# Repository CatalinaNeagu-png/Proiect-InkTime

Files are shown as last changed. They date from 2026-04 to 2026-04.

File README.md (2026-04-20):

# Proiect-InkTime
## 1. Diagrama Bloc a Sistemului
Diagrama de mai jos arata cum sunt conectate componentele principale la microcontroller-ul nRF52840:

- **Alimentare:** USB-C -> BQ25180 (Charger) -> Baterie LiPo 400mAh.
- **Afisaj:** Ecran E-Paper 1.54 inch (Conectat prin SPI).
- **Senzori:** Accelerometru BMA423 (Conectat prin I2C).
- **Haptica:** Driver DRV2605 + Motor Vibratii (Conectat prin I2C).
- **Interactiune:** 3 Butoane Tactile (Conectate prin GPIO).
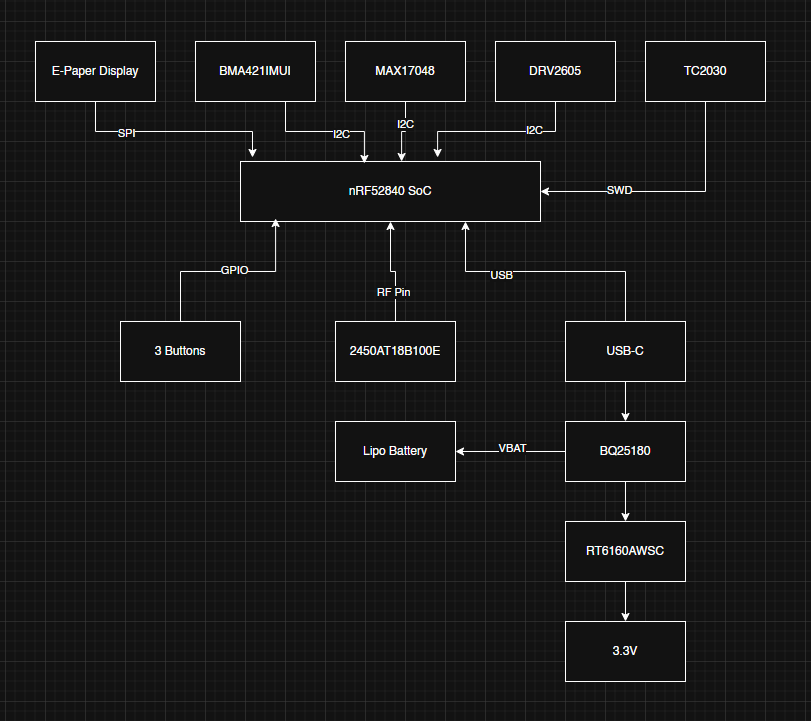
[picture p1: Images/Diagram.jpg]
Diagram


## 2. Bill of Materials (BOM)
Componente selectate din catalogul JLCPCB:

| Componenta | Producator | JLC Part Number | Datasheet |
| :--- | :--- | :--- | :--- |
| MCU nRF52840 | Nordic Semi | C190733 | [Datasheet](https://infocenter.nordicsemi.com/pdf/nRF52840_PS_v1.0.pdf) |
| Senzor BMA423 | Bosch | C404044 | [Datasheet](https://www.bosch-sensortec.com/media/boschsensortec/downloads/datasheets/bst-bma423-ds004.pdf) |
| Charger BQ25180 | TI | C2907481 | [Datasheet](https://www.ti.com/lit/ds/symlink/bq25180.pdf) |
| Driver DRV2605L | TI | C63523 | [Datasheet](https://www.ti.com/lit/ds/symlink/drv2605l.pdf) |
| Antena 2.45GHz | Johanson | C105252 | [Datasheet](https://www.johansontechnology.com/datasheets/2450AT18B100.pdf) |

## 3. Functionalitate Hardware
Dispozitivul foloseste nRF52840 pentru gestionarea comunicatiei Bluetooth Low Energy.

- **Display E-Paper:** Foloseste interfata **SPI**. Avantajul principal este consumul de energie zero cand imaginea este statica.
- **Senzori:** Accelerometrul BMA423 (interfata **I2C**) detecteaza miscarea si pasii.
- **Haptica:** Driverul DRV2605L (interfata **I2C**) controleaza motorul de vibratii pentru alerte.
- **Consum:** S-a calculat un consum in standby de aproximativ 20uA, ceea ce asigura o durata de viata a bateriei de peste 30 de zile.

## 4. Mapare Pini nRF52840

| Functie | Pin nRF | Interfata | Justificare |
| :--- | :--- | :--- | :--- |
| SPI SCK | P0.20 | SPI | Ceas pentru ecran |
| SPI MOSI | P0.21 | SPI | Date pentru ecran |
| SPI CS | P0.22 | SPI | Selectie ecran |
| I2C SDA | P0.26 | I2C | Date senzori/charger |
| I2C SCL | P0.27 | I2C | Ceas senzori/charger |
| Buton Sus | P0.11 | GPIO | Intrare navigare |
| Buton OK | P0.12 | GPIO | Intrare selectie |
| Buton Jos | P0.13 | GPIO | Intrare navigare |

## 5. Design si Integrare Mecanica
- **Aliniere:** Butoanele tactile sunt plasate la Y=3mm pentru a se potrivi cu decupajele carcasei WearAware.
- **Antena:** Are o zona dedicata "keep-out" fara cupru pentru a nu bloca semnalul Bluetooth.
- **Asamblare:** Componentele sunt asezate tip "sandwich": Carcasa -> Display -> PCB -> Baterie.

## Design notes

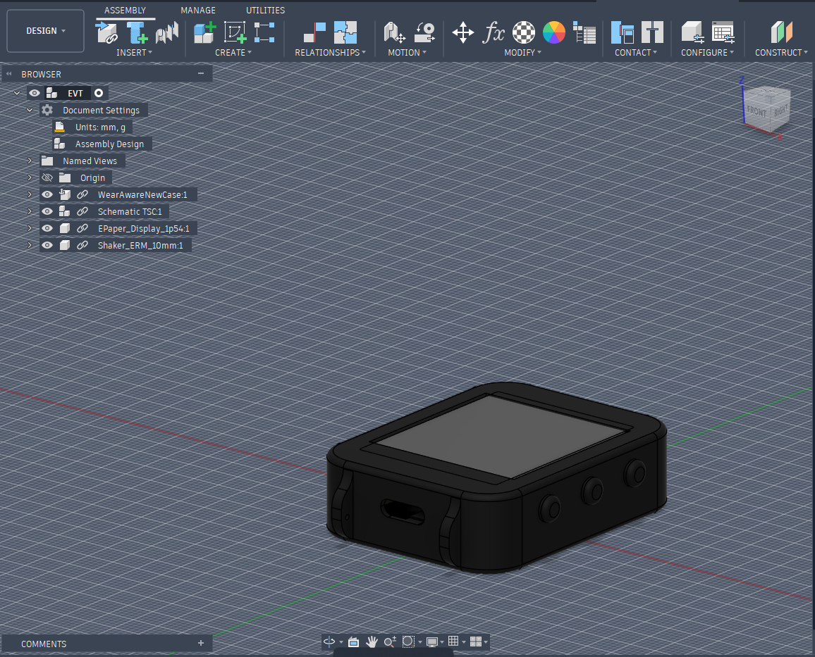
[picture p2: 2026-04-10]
Images/Screenshot 2026-04-10 175402.png

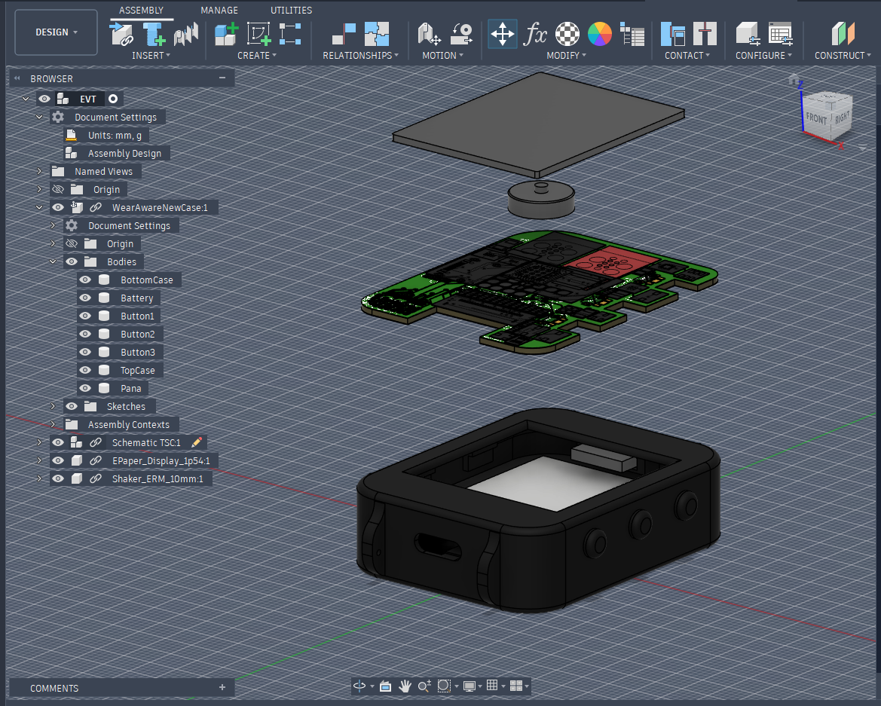
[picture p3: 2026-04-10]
Images/Screenshot 2026-04-10 174944.png

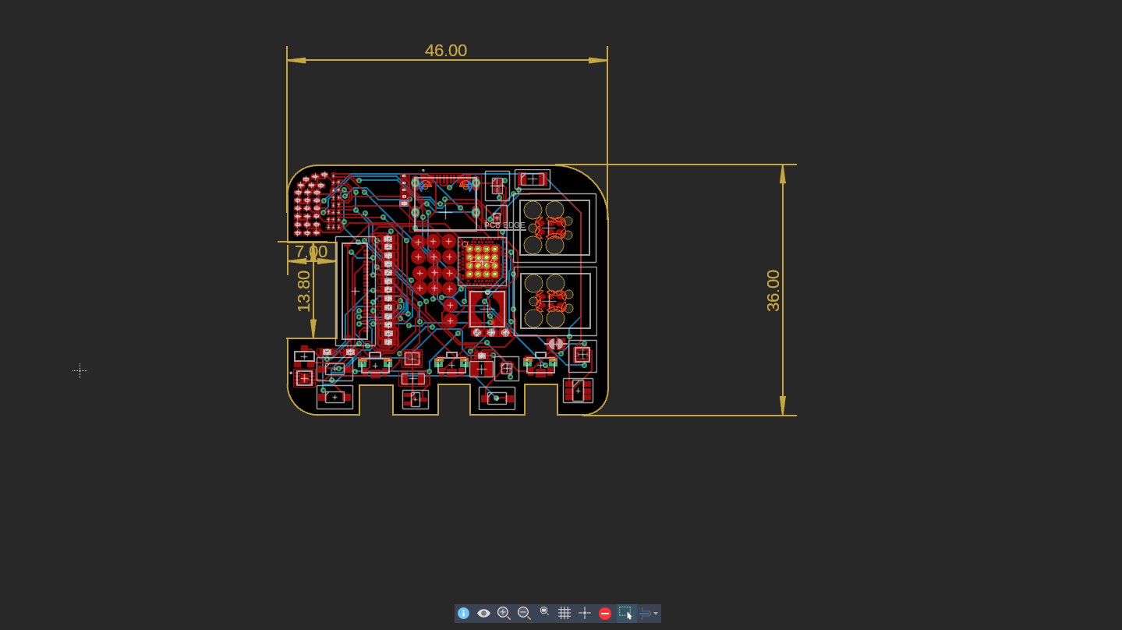
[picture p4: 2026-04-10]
Images/Screenshot 2026-04-10 175436.png

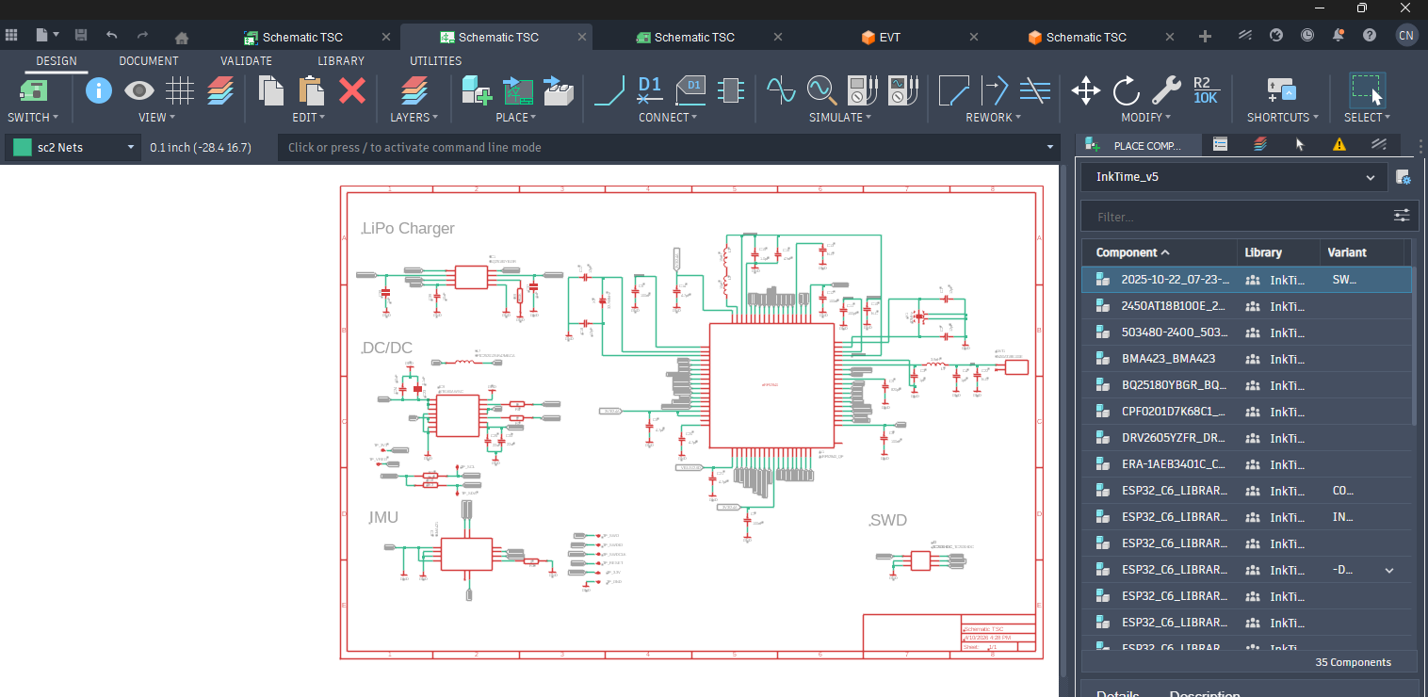
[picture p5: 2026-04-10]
Images/Screenshot 2026-04-10 175542.png

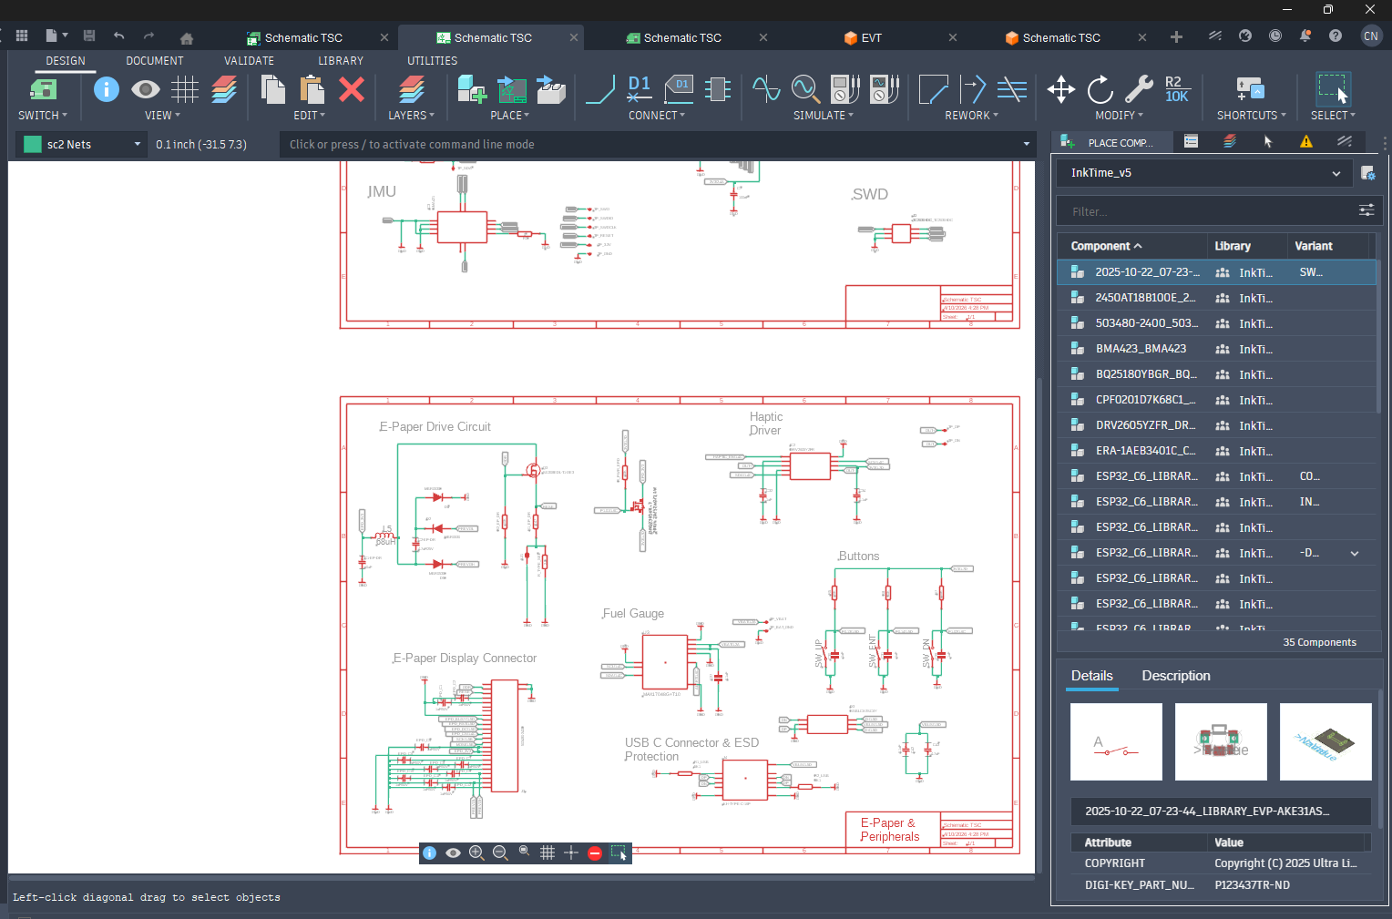
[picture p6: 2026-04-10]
Images/Screenshot 2026-04-10 175555.png

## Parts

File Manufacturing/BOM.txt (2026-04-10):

Partlist exported from Fusion Hub: Laborator TSC   Project: Default Project  Board: Schematic TSC at 4/10/2026 5:35 PM

Qty Value                                                   Device                                                                       Package                                                                                                                Parts                                                                                                                      Description                                                                                                               ARROW_PART_NUMBER ARROW_PRICE-STOCK                                                                                AVAILABILITY CHECK_PRICES                                                                       COPYRIGHT                                                DESCRIPTION                                                                                                                                                                         DIGI-KEY_PART_NUMBER_1                    DIGI-KEY_PART_NUMBER_2 DIGI-KEY_PART_NUMBER_3                              HEIGHT  JLCPCB MANUFACTURER_NAME   MANUFACTURER_PART_NUMBER                                         MF                 MFR_NAME          MOUSER_PART_NUMBER MOUSER_PRICE-STOCK                                                                                           MP                                                                                                       PACKAGE                     POPULARITY PRICE            PROD_ID                      PURCHASE-URL                                                                                                                               SNAPEDA_LINK                                                                      SPICEMODEL SPICEPREFIX                                                                                                                                     TP_SIGNAL_NAME                                                                      VALUE             
1                                                           ESP32_C6_LIBRARY_7_JUMPER_SJ                                                 ESP32_C6_LIBRARY_7_JUMPER_SJ                                                                                           SJ1                                                                                                                        SMD solder JUMPER                                                                                                                                                                                                                                                                                                                                                                                                                                                                                                                                                                                                                                                                                                                                                                                                                                                                                                                                                                                                                                                                                                            3                                                                                                                                                                                                                                                                                                                                                                                                                                                                                                                                                      
3   0                                                       CPF0201D7K68C1_CPF0201D7K68C1                                                CPF0201D7K68C1_0201                                                                                                    R2, R3, R4                                                                                                                 7.68k 0201 Thin Film Surface Mount Fixed Resistor +/-0.5% 0.031W CPF0201D7K68C1                                                                                                                                                                                                                                                                                                                                                                                                                                                                                                                                                                                                                                                                                                                                                                                                                                                                                                                                                                                                                                                                                                                                                                                                                                                                                                                                                                                                                                                                                                                                                                                                     
2   0.1uF                                                   ESP32_C6_LIBRARY_1_ESP32_WROVER_EAGLE-LTSPICE_CC0402                         ESP32_C6_LIBRARY_1_ESP32_WROVER_EAGLE-LTSPICE_C0402                                                                    C34, C42                                                                                                                   CAPACITOR, European symbol                                                                                                                                                                                                                                                                                                                                                                                                                                                                                                                                                                                                                                                                                                                                                                                                                                                                                                                                                                                                                                                                                                                                                                                                                                                                                                                                                                                         NONE       C                                                                                                                                                                                                                                                     
1   0.1uF                                                   GRM011R60J152KE01L_1_GRM011R60J152KE01L                                      GRM011R60J152KE01L_1_0201                                                                                              C23                                                                                                                        Check availability                                                                                                                                                                                                                                                                                                                                                                                                                                                                                                                                                                                                                                                                                                                                                                                                                                                                                                                                                                                                                                                                                                                                                                                                                                                                                                                                                                                                                                                                                                                                                                                                                                                                  
1   0.1uF                                                   GRM011R60J152KE01L_2_GRM011R60J152KE01L                                      GRM011R60J152KE01L_2_CAPC0201X13N                                                                                      C27                                                                                                                        Check availability                                                                                                                                                                                                                           In Stock     https://www.snapeda.com/parts/GRM011R60J152KE01L/Murata/view-part/?ref=eda                                                                                                                        SMD Capacitor X5R(EIA) with Capacitance: 1500pF Tol. 10%. Rated Voltage: 6.3Vdc                                                                                                                                                                                                                                                                        Murata                                                                                                                                                               GRM011R60J152KE01L                                                                                       0201 Murata                            None                                                                                                                                                                                     https://www.snapeda.com/parts/GRM011R60J152KE01L/Murata/view-part/?ref=snap                                                                                                                                                                                                                                                                        
1   0.47                                                    CPF0201D7K68C1_CPF0201D7K68C1                                                CPF0201D7K68C1_0201                                                                                                    R1_EP_DR                                                                                                                   7.68k 0201 Thin Film Surface Mount Fixed Resistor +/-0.5% 0.031W CPF0201D7K68C1                                                                                                                                                                                                                                                                                                                                                                                                                                                                                                                                                                                                                                                                                                                                                                                                                                                                                                                                                                                                                                                                                                                                                                                                                                                                                                                                                                                                                                                                                                                                                                                                     
1   1.0µF                                                   NORDIC_NRF_3_CAPACITOR_0201_L                                                NORDIC_NRF_3_RESC0201_L                                                                                                C15                                                                                                                        Generic chip capacitor                                                                                                                                                                                                                                                                                                                                                                                                                                                                                                                                                                                                                                                                                                                                                                                                                                                                                                                                                                                                                                                                                                                                                                                                                                                                                                                                                                                                                                                                                                                                                                                                                                                              
4   100nF                                                   NORDIC_NRF_3_CAPACITOR_0201_L                                                NORDIC_NRF_3_RESC0201_L                                                                                                C5, C7, C8, C12                                                                                                            Generic chip capacitor                                                                                                                                                                                                                                                                                                                                                                                                                                                                                                                                                                                                                                                                                                                                                                                                                                                                                                                                                                                                                                                                                                                                                                                                                                                                                                                                                                                                                                                                                                                                                                                                                                                              
1   100pF                                                   NORDIC_NRF_3_CAPACITOR_0201_L                                                NORDIC_NRF_3_RESC0201_L                                                                                                C11                                                                                                                        Generic chip capacitor                                                                                                                                                                                                                                                                                                                                                                                                                                                                                                                                                                                                                                                                                                                                                                                                                                                                                                                                                                                                                                                                                                                                                                                                                                                                                                                                                                                                                                                                                                                                                                                                                                                              
6   10K                                                     CPF0201D7K68C1_CPF0201D7K68C1                                                CPF0201D7K68C1_0201                                                                                                    R2_EP_DR, R5, R7, R8, R9, R_PWR_EPD                                                                                        7.68k 0201 Thin Film Surface Mount Fixed Resistor +/-0.5% 0.031W CPF0201D7K68C1                                                                                                                                                                                                                                                                                                                                                                                                                                                                                                                                                                                                                                                                                                                                                                                                                                                                                                                                                                                                                                                                                                                                                                                                                                                                                                                                                                                                                                                                                                                                                                                                     
1   10uF                                                    ESP32_C6_LIBRARY_1_ESP32_WROVER_EAGLE-LTSPICE_CC0402                         ESP32_C6_LIBRARY_1_ESP32_WROVER_EAGLE-LTSPICE_C0402                                                                    C1-EP-DR                                                                                                                   CAPACITOR, European symbol                                                                                                                                                                                                                                                                                                                                                                                                                                                                                                                                                                                                                                                                                                                                                                                                                                                                                                                                                                                                                                                                                                                                                                                                                                                                                                                                                                                         NONE       C                                                                                                                                                                                                                                                     
2   10uF                                                    NORDIC_NRF_3_CAPACITOR_0201_L                                                NORDIC_NRF_3_RESC0201_L                                                                                                C24, C39                                                                                                                   Generic chip capacitor                                                                                                                                                                                                                                                                                                                                                                                                                                                                                                                                                                                                                                                                                                                                                                                                                                                                                                                                                                                                                                                                                                                                                                                                                                                                                                                                                                                                                                                                                                                                                                                                                                                              
1   10µH                                                    NORDIC_NRF_2_INDUCTOR_0402_L                                                 NORDIC_NRF_2_RESC0402_L                                                                                                L2                                                                                                                         Generic chip inductor
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

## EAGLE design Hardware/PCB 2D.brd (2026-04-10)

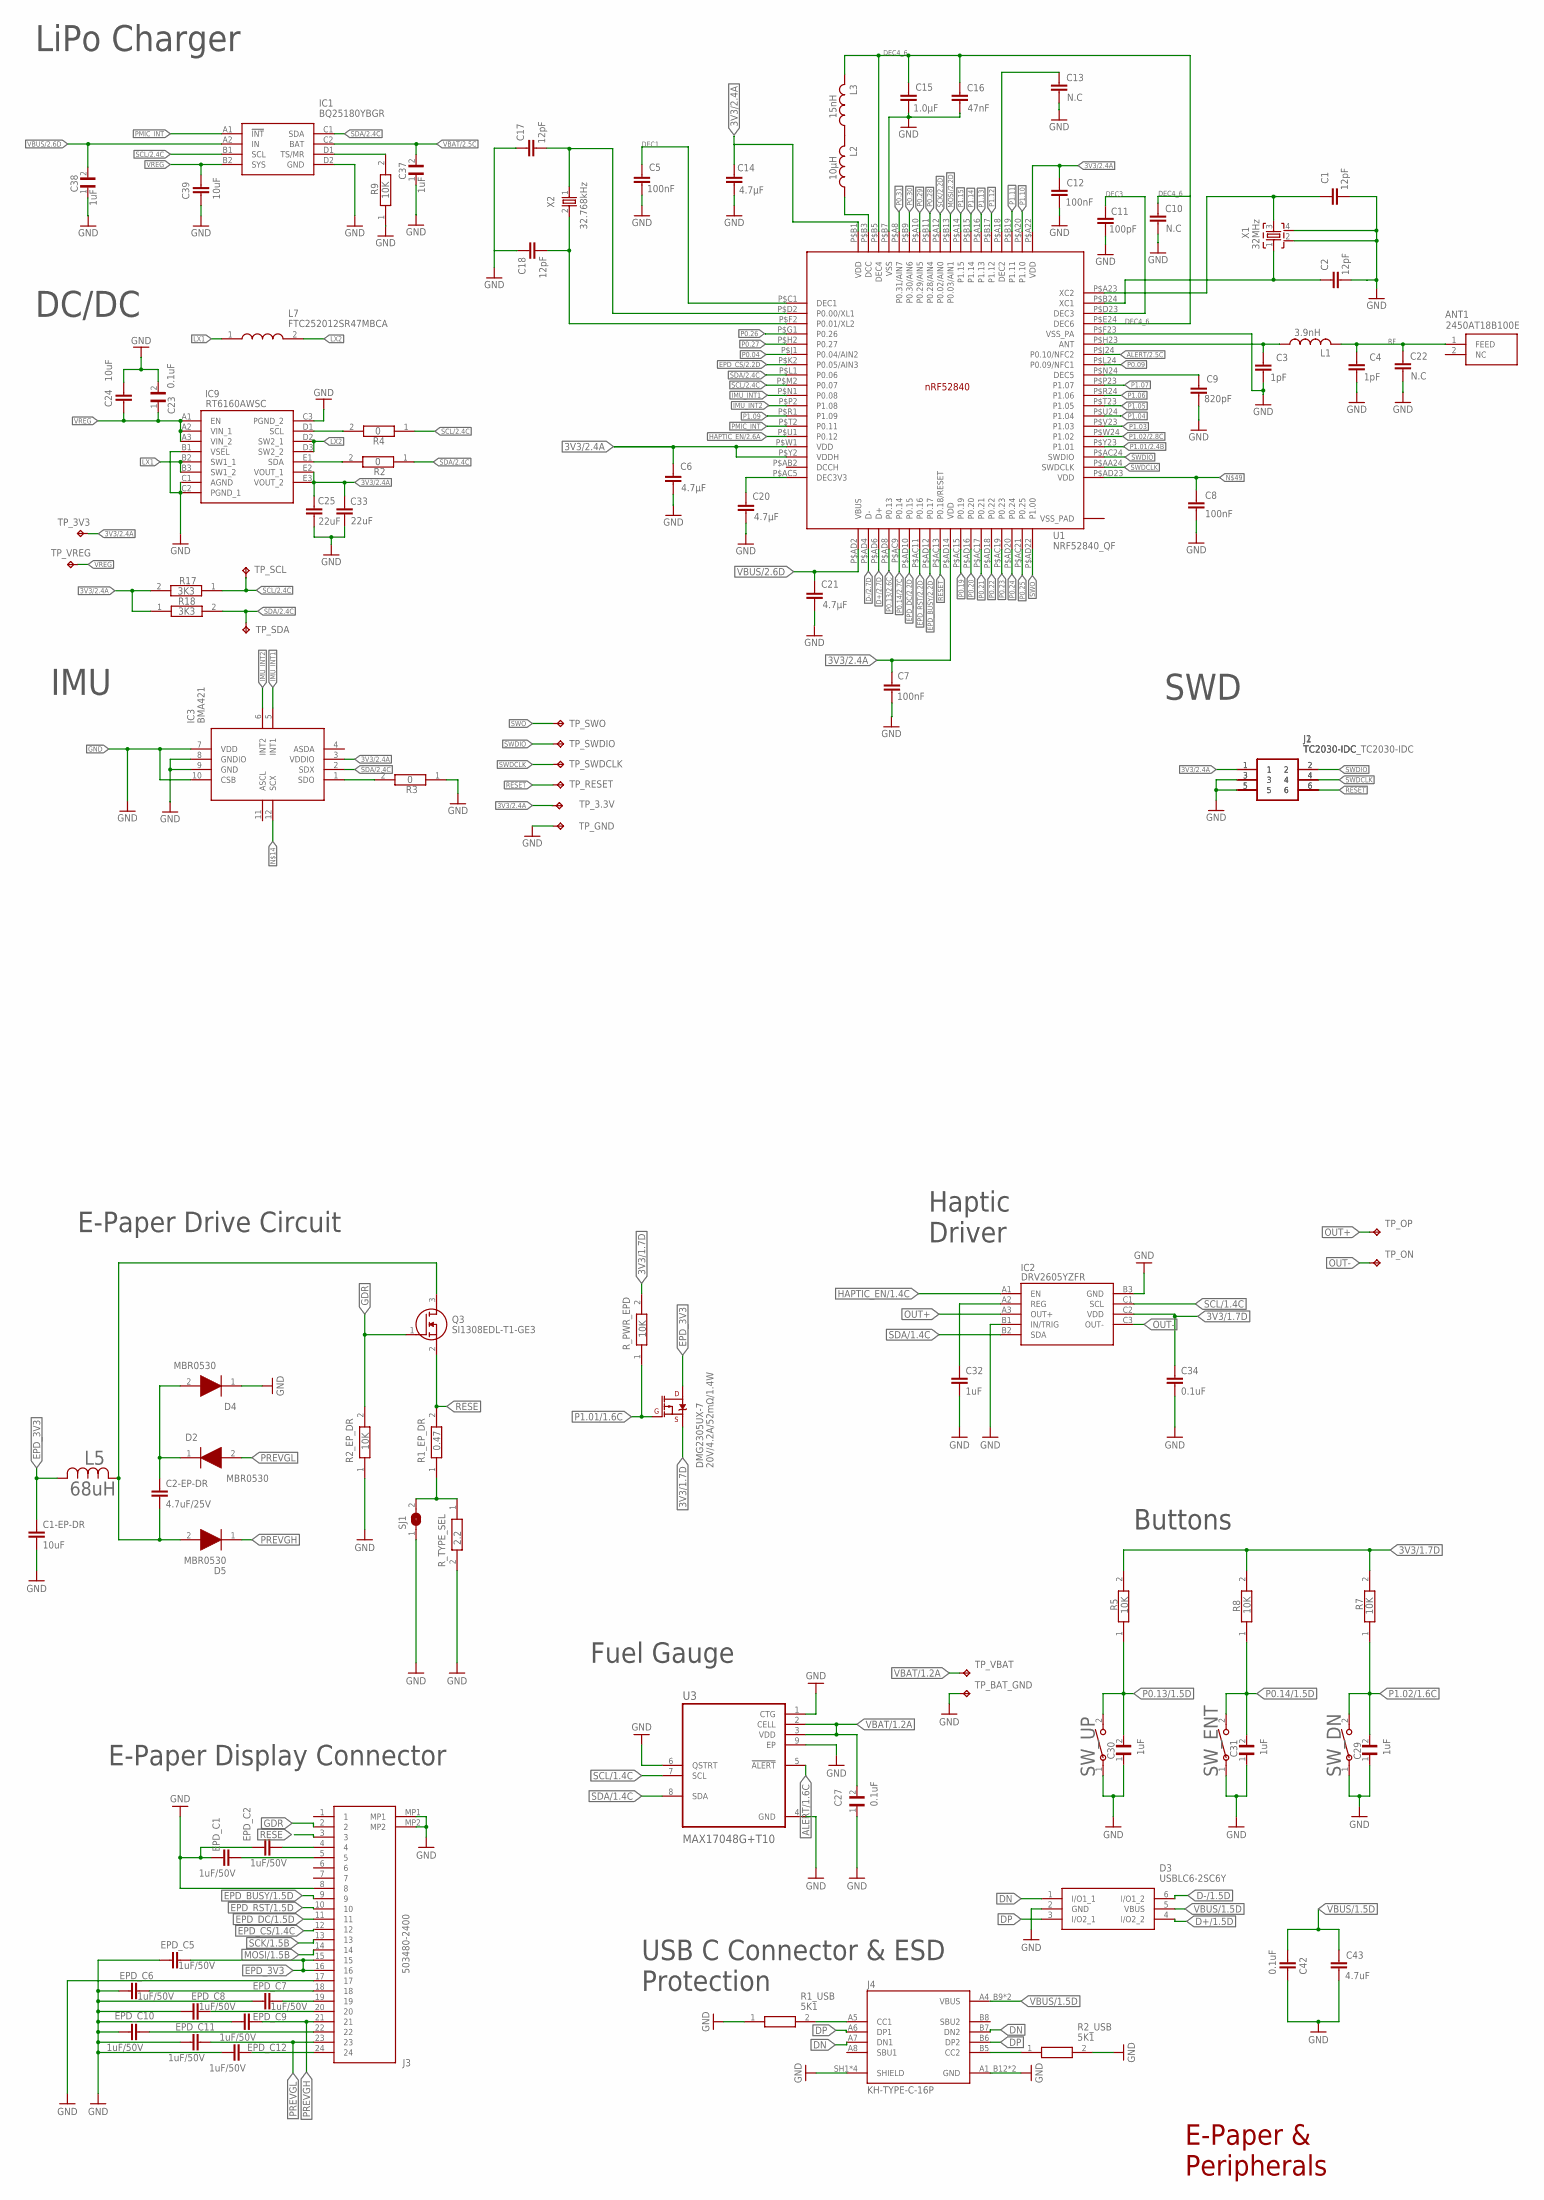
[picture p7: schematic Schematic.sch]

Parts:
ANT1: 2450AT18B100E; 2450AT18B100E_ANTC3216X140N
C1, C2, C17, C18: 12pF; NORDIC_NRF_3_RESC0201_L
C1-EP-DR: 10uF; ESP32_C6_LIBRARY_1_ESP32_WROVER_EAGLE-LTSPICE_C0402
C2-EP-DR: 4.7uF/25V; ESP32_C6_LIBRARY_1_ESP32_WROVER_EAGLE-LTSPICE_C0402
C3, C4: 1pF; NORDIC_NRF_3_RESC0201_L
C5, C7, C8, C12: 100nF; NORDIC_NRF_3_RESC0201_L
C6, C14, C20, C21: 4.7µF; NORDIC_NRF_3_RESC0201_L
C9: 820pF; NORDIC_NRF_3_RESC0201_L
C10, C13, C22: N.C; NORDIC_NRF_3_RESC0201_L
C11: 100pF; NORDIC_NRF_3_RESC0201_L
C15: 1.0µF; NORDIC_NRF_3_RESC0201_L
C16: 47nF; NORDIC_NRF_3_RESC0201_L
C23: 0.1uF; GRM011R60J152KE01L_1_0201
C24, C39: 10uF; NORDIC_NRF_3_RESC0201_L
C25, C33: 22uF; NORDIC_NRF_3_RESC0201_L
C27: 0.1uF; GRM011R60J152KE01L_2_CAPC0201X13N
C29, C30, C31: 1uF; GRM011R60J152KE01L_2_CAPC0201X13N
C32: 1uF; ESP32_C6_LIBRARY_1_ESP32_WROVER_EAGLE-LTSPICE_C0402
C34, C42: 0.1uF; ESP32_C6_LIBRARY_1_ESP32_WROVER_EAGLE-LTSPICE_C0402
C37, C38: 1uF; GRM011R60J152KE01L_1_0201
C43: 4.7uF; ESP32_C6_LIBRARY_1_ESP32_WROVER_EAGLE-LTSPICE_C0402
D2, D4: MBR0530; ESP32_C6_LIBRARY_5_SOD3716X135N
D3: USBLC6-2SC6Y; ESP32_C6_LIBRARY_3_SOT95P280X145-6N
DMG2305UX-7: 20V/4.2A/52mΩ/1.4W; ESP32_C6_LIBRARY_4_ESP32_C6_LIBRARY_4_ESP32_C6_LIBRARY_4_ES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
EPD_C1, EPD_C2, EPD_C5, EPD_C6, EPD_C7, EPD_C8, EPD_C9, EPD_C10, EPD_C11, EPD_C12: 1uF/50V; ESP32_C6_LIBRARY_1_ESP32_WROVER_EAGLE-LTSPICE_C0402
IC1: BQ25180YBGR; BQ25180YBGR_BGA8C40P2X4_100X155X50
IC2: DRV2605YZFR; DRV2605YZFR_BGA9C50P3X3_144X144X62
IC3: BMA421; BMA423_BMA423
IC9: RT6160AWSC; RT6160AWSC_BGA15C40P3X5_140X230X60
J1: TC2030-IDC_TC2030-IDC; TC2030-IDC_TC2030IDC
J2: TC2030-IDC; TC2030-IDC_TC2030IDC
J3: 503480-2400; 503480-2400_5034802400
J4: KH-TYPE-C-16P; KH-TYPE-C-16P_KINGHELM_KH-TYPE-C-16P
L1: 3.9nH; NORDIC_NRF_2_RESC0402_L
L2: 10µH; NORDIC_NRF_2_RESC0402_L
L3: 15nH; NORDIC_NRF_2_RESC0402_L
L5: 68uH; ESP32_C6_LIBRARY_2_IND_4828-WE-TPC_WRE
L7: FTC252012SR47MBCA; MLP2016SR47MT0S1_INDC2016X100N
MBR0530: D5; ESP32_C6_LIBRARY_5_SOD3716X135N
Q3: SI1308EDL-T1-GE3; ESP32_C6_LIBRARY_6_SOT65P210X110-3N
R1_EP_DR: 0.47; CPF0201D7K68C1_0201
R1_USB, R2_USB: 5K1; CPF0201D7K68C1_0201
R2, R3, R4: 0; CPF0201D7K68C1_0201
R2_EP_DR, R5, R7, R8, R9: 10K; CPF0201D7K68C1_0201
R17, R18: 3K3; CPF0201D7K68C1_0201
R_PWR_EPD: 10K; CPF0201D7K68C1_0201
R_TYPE_SEL: 2.2; CPF0201D7K68C1_0201
SJ1: ESP32_C6_LIBRARY_7_JUMPER_SJ
SW_DN: 2025-10-22_07-23-44_LIBRARY_EVP-AKE31ASW_EVP-AKE3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; 2025-10-22_07-23-44_LIBRARY_SW_EVP-AKE31A_PAN
SW_ENT: 2025-10-22_07-23-44_LIBRARY_EVP-AKE31ASW_EVP-AKE3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; 2025-10-22_07-23-44_LIBRARY_SW_EVP-AKE31A_PAN
SW_UP: 2025-10-22_07-23-44_LIBRARY_EVP-AKE31ASW_EVP-AKE3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; 2025-10-22_07-23-44_LIBRARY_SW_EVP-AKE31A_PAN
TP_3.3V, TP_3V3: HECTOR_WATCH_1_TPTP20R; HECTOR_WATCH_1_TP20R
TP_BAT_GND: HECTOR_WATCH_1_TPTP20R; HECTOR_WATCH_1_TP20R
TP_GND: HECTOR_WATCH_1_TPTP20R; HECTOR_WATCH_1_TP20R
TP_ON: HECTOR_WATCH_1_TPTP20R; HECTOR_WATCH_1_TP20R
TP_OP: HECTOR_WATCH_1_TPTP20R; HECTOR_WATCH_1_TP20R
TP_RESET: HECTOR_WATCH_1_TPTP20R; HECTOR_WATCH_1_TP20R
TP_SCL: HECTOR_WATCH_1_TPTP20R; HECTOR_WATCH_1_TP20R
TP_SDA: HECTOR_WATCH_1_TPTP20R; HECTOR_WATCH_1_TP20R
TP_SWDCLK: HECTOR_WATCH_1_TPTP20R; HECTOR_WATCH_1_TP20R
TP_SWDIO: HECTOR_WATCH_1_TPTP20R; HECTOR_WATCH_1_TP20R
TP_SWO: HECTOR_WATCH_1_TPTP20R; HECTOR_WATCH_1_TP20R
TP_VBAT: HECTOR_WATCH_1_TPTP20R; HECTOR_WATCH_1_TP20R
TP_VREG: HECTOR_WATCH_1_TPTP20R; HECTOR_WATCH_1_TP20R
U1: NRF52840_QF; NORDIC_NRF_4_AQFN50P700X700X85_HS-74N
U3: MAX17048G+T10; ESP32_C6_LIBRARY_SON50P200X200X80-9N
X1: 32MHz; NORDIC_NRF_BT-XTAL_2016_N
X2: 32.768kHz; NORDIC_NRF_1_XTAL_3215_N

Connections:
3V3/1.7D: C34.1, DMG2305UX-7.2 (S), IC2.C2 (VDD), R5.2, R7.2, R8.2, R_PWR_EPD.2
3V3/2.4A: C6.1, C25.1, IC3.3 (VDDIO), IC9.E2 (VOUT_1), IC9.E3 (VOUT_2), J1.1, J2.1, R17.2, R18.1, U1.P$A22 (VDD), U1.P$AD14 (VDD), U1.P$W1 (VDD)
ALERT/1.6C: U3.5 (!ALERT)
ALERT/2.5C: U1.P$J24 (P0.10/NFC2)
D+/1.5D: D3.4 (I/O2_2)
D+/2.7D: U1.P$AD6 (D+)
D-/1.5D: D3.6 (I/O1_2)
D-/2.7D: U1.P$AD4 (D-)
DEC1: C5.1, U1.P$C1 (DEC1)
DEC3: C11.1, U1.P$D23 (DEC3)
DEC4_6: C10.1, L3.2, U1.P$E24 (DEC6)
DN: D3.1 (I/O1_1), J4.A7 (DN1), J4.B7 (DN2)
DP: D3.3 (I/O2_1), J4.A6 (DP1), J4.B6 (DP2)
EPD_3V3: C1-EP-DR.1, DMG2305UX-7.3 (D), EPD_C5.2, J3.15, J3.16, L5.2
EPD_BUSY/1.5D: J3.9
EPD_BUSY/2.2D: U1.P$AD12 (P0.17)
EPD_CS/1.4C: J3.12
EPD_CS/2.2D: U1.P$K2 (P0.05/AIN3)
EPD_DC/1.5D: J3.11
EPD_DC/2.2D: U1.P$AD10 (P0.15)
EPD_RST/1.5D: J3.10
EPD_RST/2.2D: U1.P$AC11 (P0.16)
GDR: J3.2, Q3.1 (G), R2_EP_DR.2
GND: C1.2, C1-EP-DR.2, C3.2, C4.2, C5.2, C6.2, C7.2, C8.2, C9.2, C10.2, C11.2, C12.2, C13.2, C14.2, C15.2, C17.1, C20.2, C21.2, C22.2, C23.2, C24.1, C25.2, C27.1, C29.1, C30.1, C31.1, C32.2, C33.2, C34.2, C37.1, C38.1, C39.2, C42.2, C43.1, D3.2 (GND), D4.1 (K), EPD_C1.1, EPD_C2.1, EPD_C5.1, EPD_C6.1, EPD_C7.1, EPD_C8.1, EPD_C9.1, EPD_C10.1, EPD_C11.1, EPD_C12.1, IC1.D2 (GND), IC2.B1 (IN/TRIG), IC2.B3 (GND), IC3.7 (VDD), IC3.10 (CSB), IC9.B1 (VSEL), IC9.C1 (AGND), IC9.C2 (PGND_1), IC9.C3 (PGND_2), J1.3, J1.5, J2.3, J2.5, J3.8, J3.17, J3.MP1, J3.MP2, J4.A1_B12 (GND), J4.A12_B1 (GND), J4.SH1 (SHIELD), J4.SH2 (SHIELD), J4.SH3 (SHIELD), J4.SH4 (SHIELD), R1_USB.1, R2_EP_DR.1, R2_USB.2, R3.1, R9.1, R_TYPE_SEL.2, SJ1.1, SW_DN.1, SW_ENT.1, SW_UP.1, TP_BAT_GND.TP, U3.1 (CTG), U3.4 (GND), U3.6 (QSTRT), U3.9 (EP)
HAPTIC_EN/1.4C: IC2.A1 (EN)
HAPTIC_EN/2.6A: U1.P$U1 (P0.12)
IMU_INT1: IC3.5 (INT1), U1.P$N1 (P0.08)
IMU_INT2: IC3.6 (INT2), U1.P$P2 (P1.08)
LX1: IC9.B2 (SW1_1), IC9.B3 (SW1_2), L7.1
LX2: IC9.D2 (SW2_1), IC9.D3 (SW2_2), L7.2
MOSI/1.5B: J3.14
MOSI/2.2D: U1.P$B13 (P0.03/AIN1)
unnamed: IC1.D1 (TS/MR), R9.2
unnamed: IC9.D1 (SCL), R4.2
unnamed: IC9.E1 (SDA), R2.2
unnamed: IC3.8 (GNDIO), IC3.9 (GND)
unnamed: IC3.1 (SDO), R3.2
unnamed: C2-EP-DR.2, L5.1, MBR0530.2 (A), Q3.3 (D)
unnamed: R18.2, TP_SDA.TP
unnamed: C14.1, U1.P$B1 (VDD)
unnamed: L2.2, L3.1
unnamed: U1.P$D2 (P0.00/XL1), X2.1
unnamed: U1.P$F2 (P0.01/XL2), X2.2
unnamed: C20.1, U1.P$AC5 (DEC3V3)
unnamed: C2-EP-DR.1, D2.1 (K), D4.2 (A)
unnamed: L2.1, U1.P$B3 (DCC)
unnamed: C16.2, U1.P$B7 (VSS)
unnamed: C13.1, U1.P$A18 (DEC2)
unnamed: C1.1, U1.P$A23 (XC2)
unnamed: C2.1, U1.P$B24 (XC1)
unnamed: C9.1, U1.P$N24 (DEC5)
unnamed: L1.1, U1.P$H23 (ANT)
unnamed: R1_EP_DR.1, R_TYPE_SEL.1, SJ1.2
unnamed: C32.1, IC2.A2 (REG)
unnamed: EPD_C2.2, J3.4
unnamed: EPD_C1.2, J3.5
unnamed: EPD_C7.2, J3.19
unnamed: EPD_C8.2, J3.20
unnamed: EPD_C10.2, J3.22
unnamed: EPD_C12.2, J3.24
unnamed: EPD_C6.2, J3.18
unnamed: J4.A5 (CC1), R1_USB.2
unnamed: J4.B5 (CC2), R2_USB.1
OUT+: IC2.A3 (OUT+), TP_OP.TP
OUT-: IC2.C3 (OUT-), TP_ON.TP
P0.04: U1.P$J1 (P0.04/AIN2)
P0.09: U1.P$L24 (P0.09/NFC1)
P0.13/1.5D: C30.2, R5.1, SW_UP.2
P0.13/2.6C: U1.P$AD8 (P0.13)
P0.14/1.5D: C31.2, R8.1, SW_ENT.2
P0.14/2.7C: U1.P$AC9 (P0.14)
P0.19: U1.P$AC15 (P0.19)
P0.20: U1.P$AD16 (P0.20)
P0.21: U1.P$AC17 (P0.21)
P0.22: U1.P$AD18 (P0.22)
P0.23: U1.P$AC19 (P0.23)
P0.24: U1.P$AD20 (P0.24)
P0.25: U1.P$AC21 (P0.25)
P0.26: U1.P$G1 (P0.26)
P0.27: U1.P$H2 (P0.27)
P0.28: U1.P$B11 (P0.28/AIN4)
P0.29: U1.P$A10 (P0.29/AIN5)
P0.30: U1.P$B9 (P0.30/AIN6)
P0.31: U1.P$A8 (P0.31/AIN7)
P1.01/1.6C: DMG2305UX-7.1 (G), R_PWR_EPD.1
P1.01/2.4B: U1.P$Y23 (P1.01)
P1.02/1.6C: C29.2, R7.1, SW_DN.2
P1.02/2.8C: U1.P$W24 (P1.02)
P1.03: U1.P$V23 (P1.03)
P1.04: U1.P$U24 (P1.04)
P1.05: U1.P$T23 (P1.05)
P1.06: U1.P$R24 (P1.06)
P1.07: U1.P$P23 (P1.07)
P1.09: U1.P$R1 (P1.09)
P1.10: U1.P$A20 (P1.10)
P1.11: U1.P$B19 (P1.11)
P1.12: U1.P$B17 (P1.12)
P1.13: U1.P$A16 (P1.13)
P1.14: U1.P$B15 (P1.14)
P1.15: U1.P$A14 (P1.15)
PMIC_INT: IC1.A1 (!INT), U1.P$T2 (P0.11)
PREVGH: EPD_C9.2, J3.21, MBR0530.1 (K)
PREVGL: D2.2 (A), EPD_C11.2, J3.23
RESE: J3.3, Q3.2 (S), R1_EP_DR.2
RESET: J1.6, J2.6, U1.P$AC13 (P0.18/RESET)
RF: ANT1.1 (FEED), L1.2
SCK/1.5B: J3.13
SCK/2.2D: U1.P$A12 (P0.02/AIN0)
SCL/1.4C: IC2.C1 (SCL), U3.7 (SCL)
SCL/2.4C: IC1.B1 (SCL), R4.1, R17.1, U1.P$M2 (P0.07)
SDA/1.4C: IC2.B2 (SDA), U3.8 (SDA)
SDA/2.4C: IC1.C1 (SDA), IC3.2 (SDX), R2.1, U1.P$L1 (P0.06)
SWDCLK: J1.4, J2.4, U1.P$AA24 (SWDCLK)
SWDIO: J1.2, J2.2, U1.P$AC24 (SWDIO)
SWO: U1.P$AD22 (P1.00)
VBAT/1.2A: C27.2, TP_VBAT.TP, U3.2 (CELL), U3.3 (VDD)
VBAT/2.5C: C37.2, IC1.C2 (BAT)
VBUS/1.5D: C42.1, C43.2, D3.5 (VBUS), J4.A4_B9 (VBUS), J4.A9_B4 (VBUS)
VBUS/2.6D: C38.2, IC1.A2 (IN), U1.P$AD2 (VBUS)
VREG: C39.1, IC1.B2 (SYS), IC9.A1 (EN), IC9.A2 (VIN_1), IC9.A3 (VIN_2)

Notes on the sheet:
LiPo Charger
DC/DC
IMU
SWD
E-Paper Drive Circuit
E-Paper Display Connector
Fuel Gauge
Buttons
USB C Connector & ESD Protection
Haptic Driver
E-Paper & Peripherals

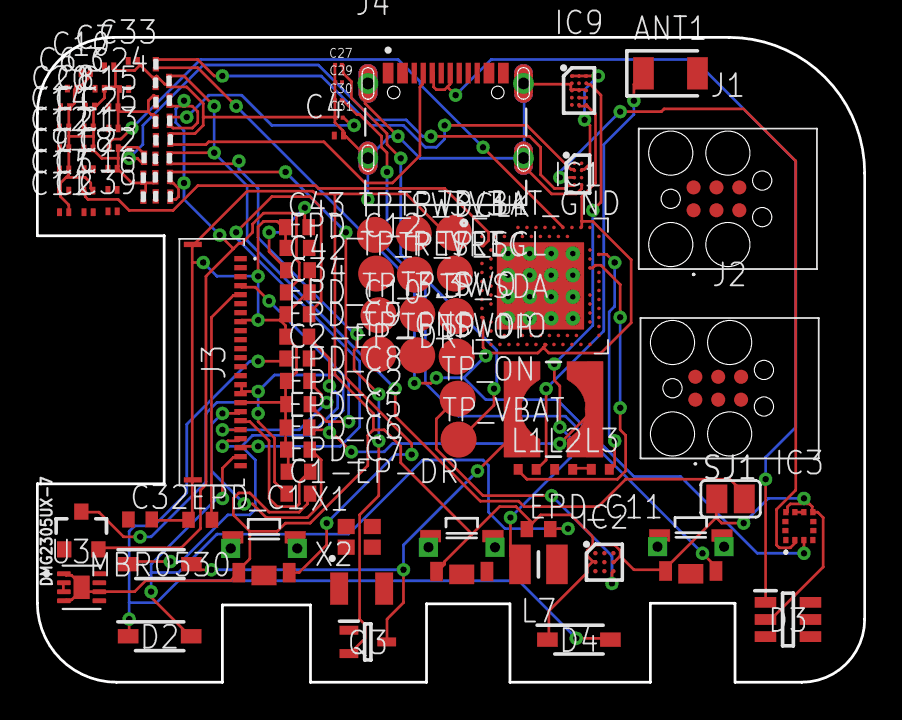
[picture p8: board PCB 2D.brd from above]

Board: 2 copper layers, 46.0 x 35.8 mm, 105 parts (0 on the bottom side), 68 nets.

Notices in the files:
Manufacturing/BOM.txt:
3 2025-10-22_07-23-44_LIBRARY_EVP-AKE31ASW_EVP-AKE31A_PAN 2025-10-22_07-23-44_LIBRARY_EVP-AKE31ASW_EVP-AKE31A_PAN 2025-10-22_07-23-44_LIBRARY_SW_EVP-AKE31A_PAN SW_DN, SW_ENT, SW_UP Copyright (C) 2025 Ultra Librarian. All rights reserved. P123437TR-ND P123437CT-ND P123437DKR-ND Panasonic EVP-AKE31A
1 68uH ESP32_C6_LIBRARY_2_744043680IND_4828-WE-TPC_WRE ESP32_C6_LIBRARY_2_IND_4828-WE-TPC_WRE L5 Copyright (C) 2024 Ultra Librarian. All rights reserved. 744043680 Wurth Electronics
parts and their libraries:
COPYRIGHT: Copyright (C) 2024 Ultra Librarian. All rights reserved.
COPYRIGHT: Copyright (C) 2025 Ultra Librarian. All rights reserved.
